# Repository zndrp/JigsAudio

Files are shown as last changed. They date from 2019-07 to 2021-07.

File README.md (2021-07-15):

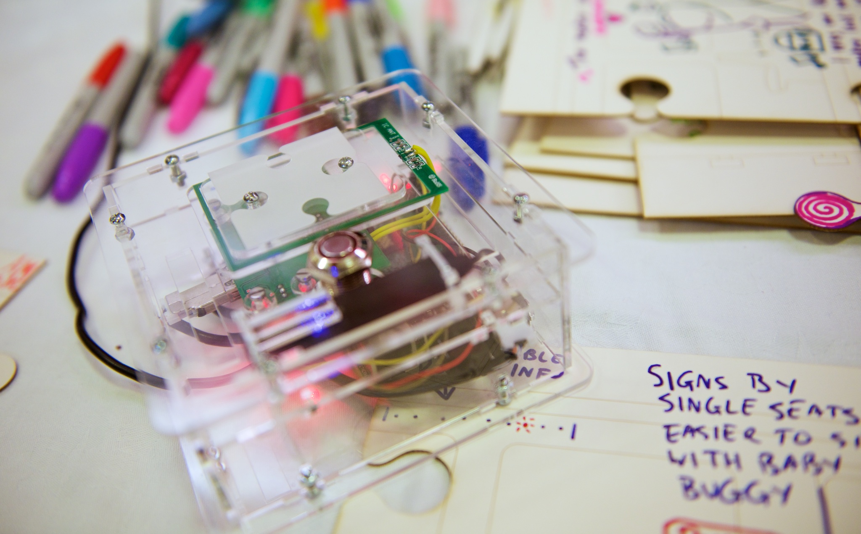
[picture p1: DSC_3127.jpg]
Image of JigsAudio


# A Few Details:

This project takes an RFID Tagged Puzzle piece and associates it with an audio clip, stored on a Raspberry Pi. I'm currently  writing instructions on how to make your own JigsAudio device, but in the meantime, please do email me: alexander.wilson@ncl.ac.uk

If you're interesting in how JigsAudio was used, you can read about it in this [paper](https://journals.sagepub.com/doi/full/10.1177/2399808319831290).

## What's inside?:
* **caseDesigns:** This folder contains the case designs for the different versions of JigsAudio (.ai and .svg). All of the cases are designed for laser cut 3mm material - usually 3mm perspex but you can what you'd like. The case requires M3 screws and nuts.

* **documentation:** This folder contains documentation on JigsAudio. This is a work in progesss. At the moment it contains the circuit schematic (showing where the leads for the buttons and switches go). 

* **jigsawDesigns:** This folder contains the desgins for the different jigsaw designs. These are easily created (as long as the peices are large enough for RFID tags).

* **templates:** The template folder contains the template for the webpage that will be generated to allow the device to be connected to and listen to the audio.

* **testingScripts:** These are scripts that were used to test the various functions of JigsAudio before they were added to the main script. They test functions such as the lights and buttons to make sure they're wired correctly.

* **website-generator:** These scripts will make the JigsAudio webpage that is used to share the results on a static website.

This project wouldn't be possible without the help and support of Samantha Finnigan, Andy Dow and Sebastian Mellor. Huge huge thanks to everyone that helped me.

This project wouldn't be possible without the help and support of Samantha Finnigan and Andy Dow. A huge huge thanks!

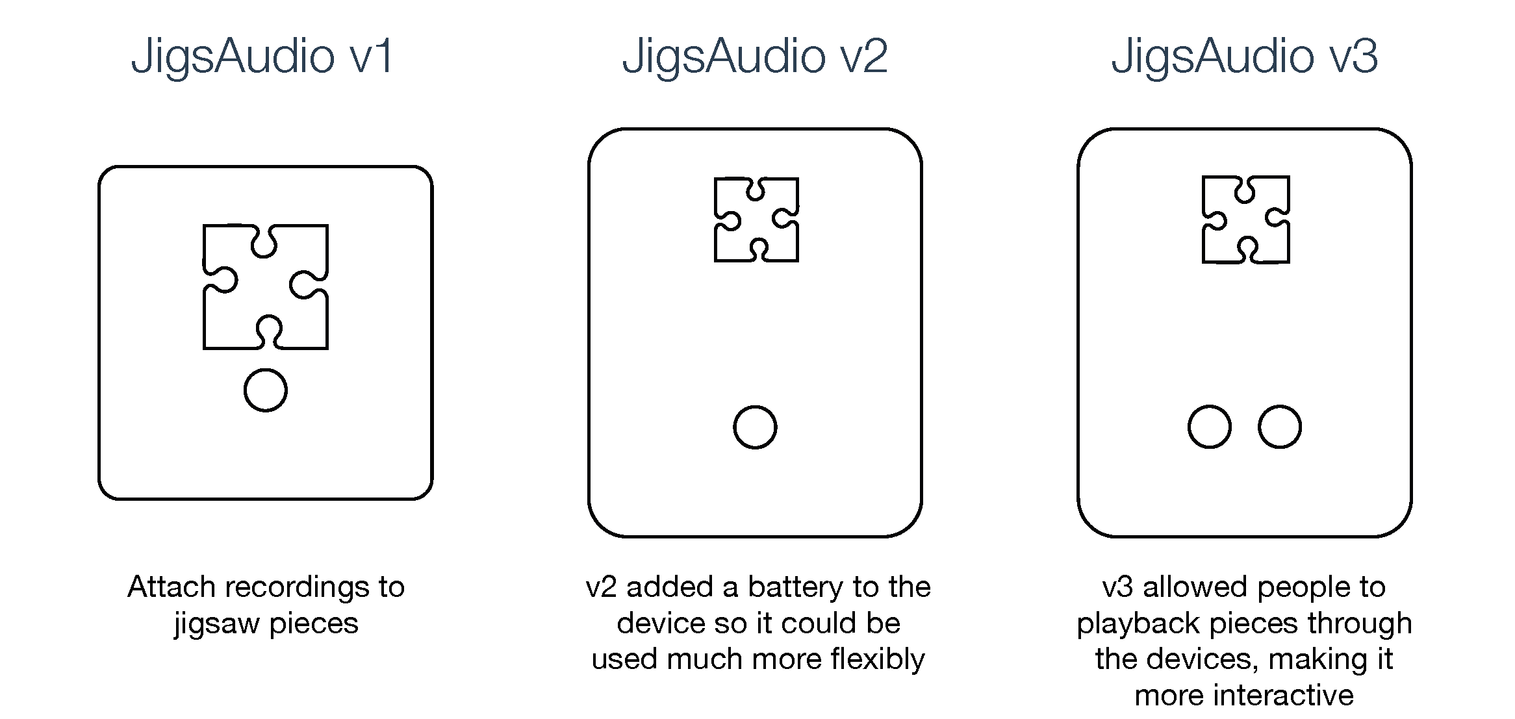
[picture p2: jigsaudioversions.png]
JigsAudio Versions

# Recommended Hardware:
The JigsAudio device is made from a number of off the shelf components, some of which are modified to fit within the case. As there are a lot of generic components within the device, the links to them change frequently. Rather than endlessly update these, the considerations for these components are listed. 
* *[USB RFID Reader](https://www.amazon.co.uk/Contactless-Proximity-Sensor-Reader-125Khz/dp/B00GS18WHS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):* USB RFID Contactless Proximity Sensor Smart: JigsAudio reads RFID tags that are attached to individual pieces. There are different types of RFID tags and readers. It’s important that these are compatible, so make sure the correct tags are purchased with the reader. When making the device, the casing for the reader is removed and the reader attached with two pieces in the top piece of the device.
* *RFID Tags - [Amazon](https://www.amazon.co.uk/gp/product/B00M5PC0FG/ref=oh_aui_detailpage_o08_s00?ie=UTF8&psc=1) or [Seritag](https://seritag.com/nfc-tags/22mm-clear-ntag213):* As above, make sure that the tags are compatible with the reader.
* *[Raspberry Pi](https://www.raspberrypi.org/products/raspberry-pi-2-model-b/):* Use a model of Raspberry Pi – most of them should work. The case is designed for full size RPs.
* *2x 16mm Momentary Push Button:* Make sure resistors are used for the LEDs within the buttons, particularly if using buttons with lower voltages than the RPi provides.
* *[USB Microphone](https://www.amazon.co.uk/Kinobo-Microphone-Desktops-Dictation-Software/dp/B00NSOWWIS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):* A generic USB microphone is used that is attached to the top case with cable ties. A cheap mic is used. Note: the sound quality playing from the RPi isn’t particually good – there is no dedicated sound card within the device. A USB sound quality can be added to JigsAudio if the audio quality is important
* *WiFI Adaptor:* (if not built into the RPi): Allows for the website to be served from the device, and to listen to and delete recordings, and verify the device is working.

# Some Final Things:
To have the JigsAudio Python script run at startup, you need to change the .bashrc file. This file can be found by typing: `sudo nano /home/pi/.bashrc` (You'll need to enter your password). When you find the file, add the following lines to the end of the file:

```
sudo nano /home/pi/.bashrc
echo Running at boot
sudo python /home/pi/JigsAudio/main.py 
```
    
Exit `ctrl + x` and reboot `sudo reboot now`

There's a few other things to do, such as set the volume of the headphones: 

Turn off Desktop Boot & Force Headphones
```
sudo raspi-config
```
Boot options > Desktop/CLI > Console Autologin
Advanced > Force Headphones

```
sudo Alsamixer
```
Turn volume up to full (using the arrow keys)

Restart the RPi
```
sudo reboot now
```

..it should now start up running JigsAudio.

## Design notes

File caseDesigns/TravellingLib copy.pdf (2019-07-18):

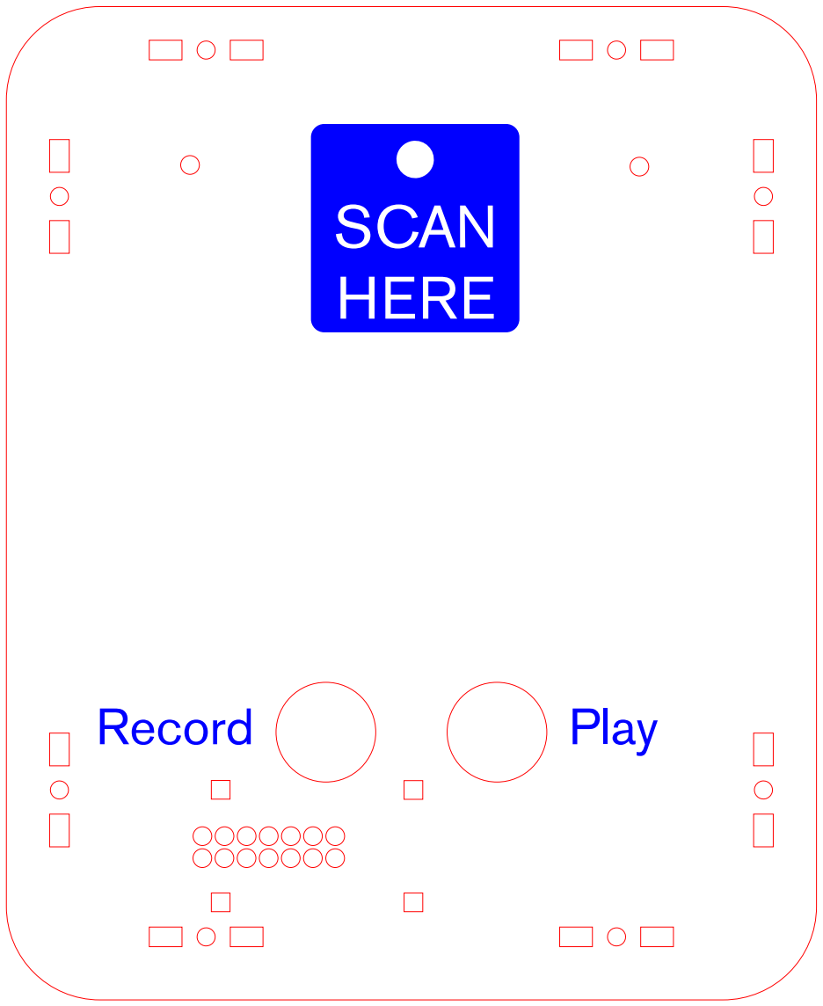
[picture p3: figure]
Record; Play; SCAN HERE

### Making a Recording

Grab a square from below
Draw your response
Scan your square and press the red button to record
Talk about your square
Press the red button to finish

### Listening to a Square

Scan someone else’s square Press the green button

BALTIC would like to acknowledge and thank Newcastle University’s Open Lab and Newcastle City Futures for JigsAudio.

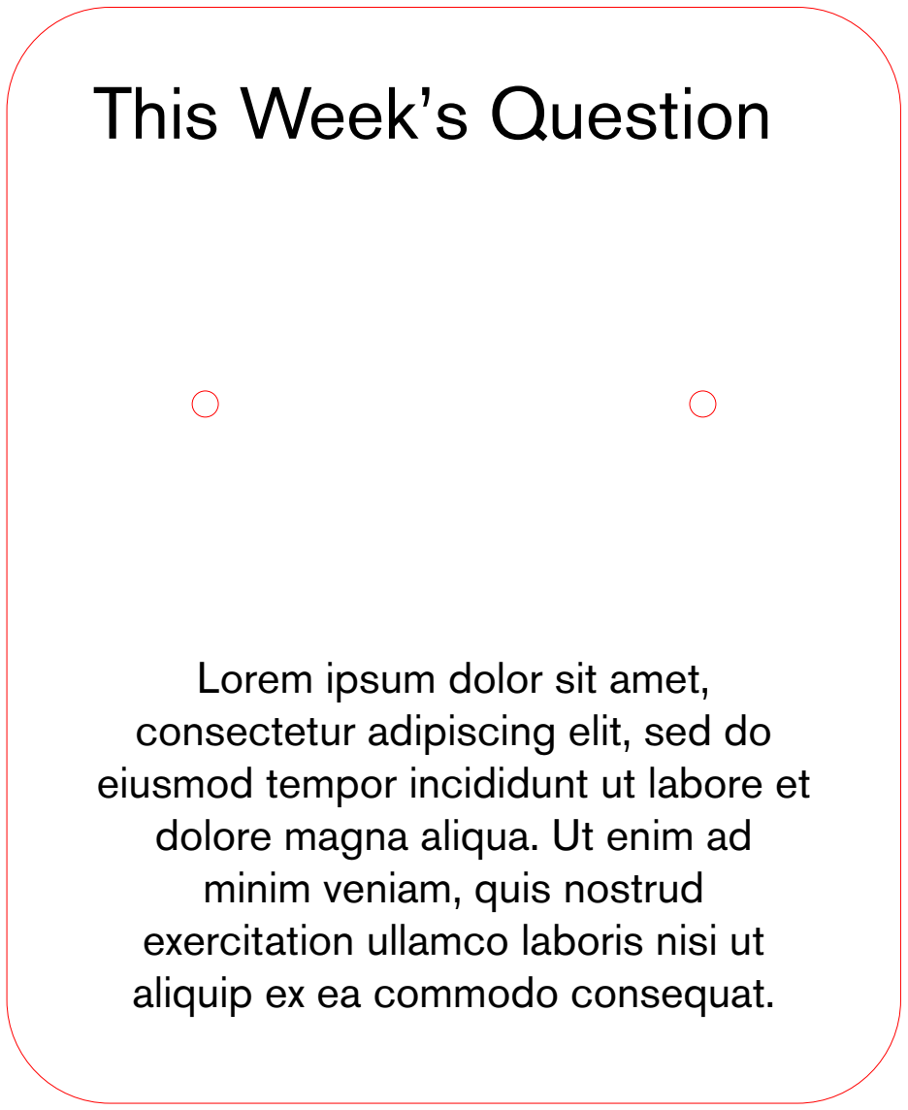
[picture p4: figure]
Lorem ipsum dolor sit amet, consectetur adipiscing elit, sed do eiusmod tempor incididunt ut labore et dolore magna aliqua. Ut enim ad minim veniam, quis nostrud exercitation ullamco laboris nisi ut aliquip ex ea commodo consequat.

Using JigsAudio | This Week’s Question

### If you could have

one superpower,

### what would it be?

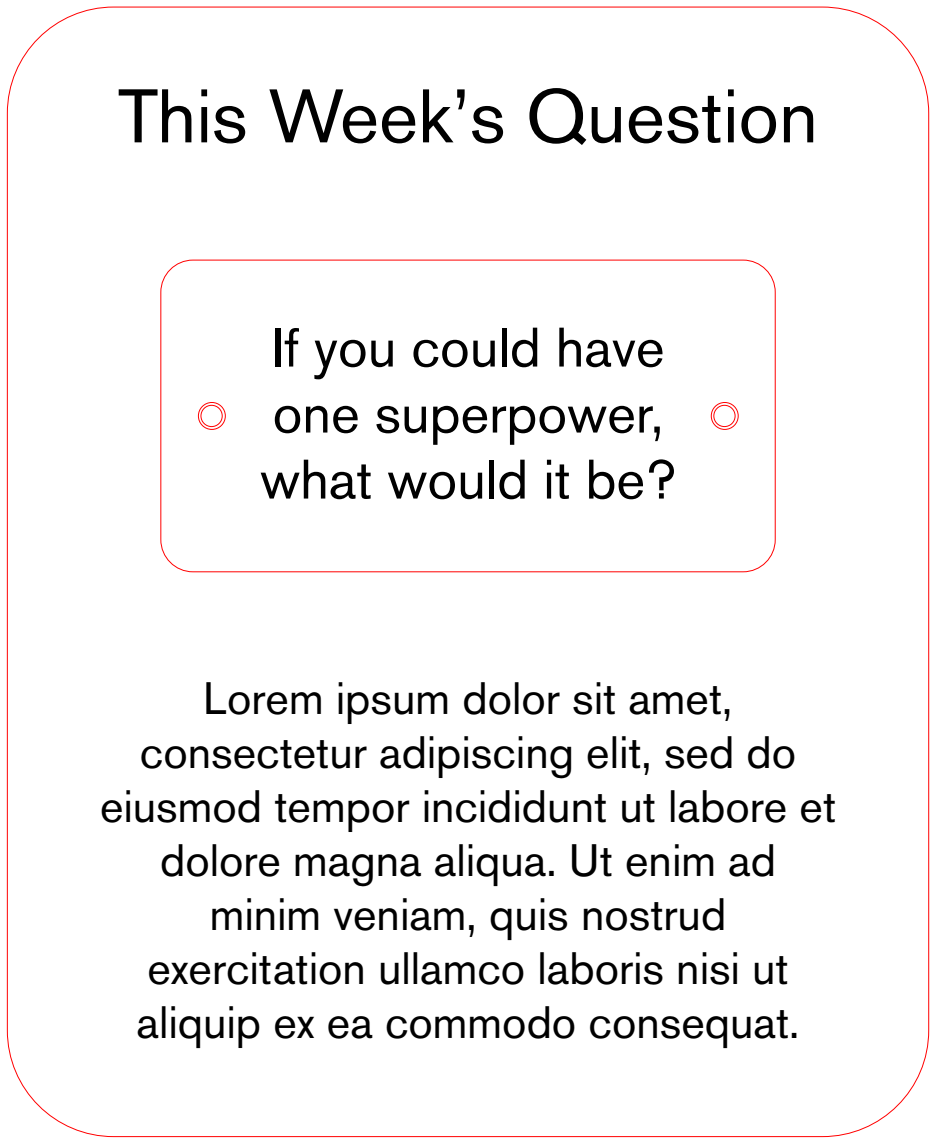
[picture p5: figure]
Lorem ipsum dolor sit amet, consectetur adipiscing elit, sed do eiusmod tempor incididunt ut labore et dolore magna aliqua. Ut enim ad minim veniam, quis nostrud exercitation ullamco laboris nisi ut aliquip ex ea commodo consequat.; This Week’s Question; If you could have one superpower, what would it be?

### What’s your favourite thing about where you live?

### How much wood could a woodchuck chuck?

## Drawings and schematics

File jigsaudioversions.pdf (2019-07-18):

JigsAudio v1 | JigsAudio v2 | JigsAudio v3

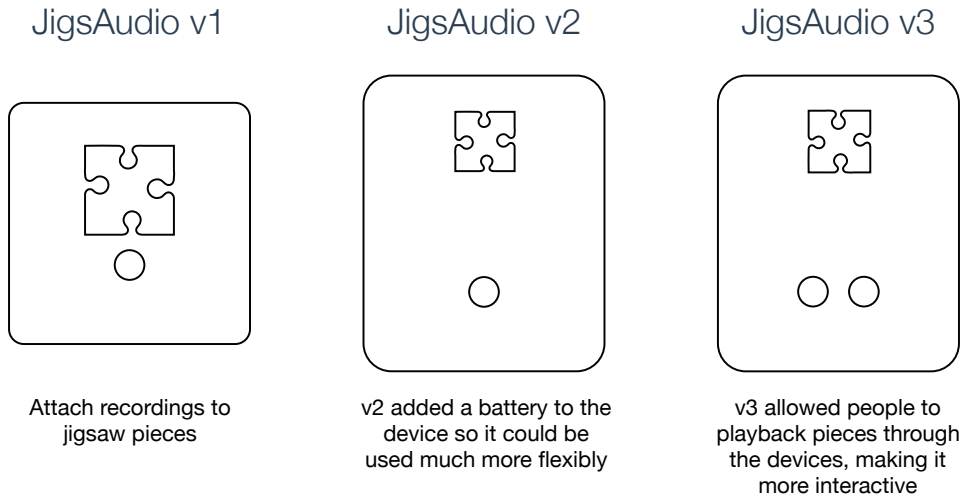
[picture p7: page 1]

Attach recordings to
jigsaw pieces

v2 added a battery to the
device so it could be
used much more flexibly

v3 allowed people to
playback pieces through
the devices, making it
more interactive

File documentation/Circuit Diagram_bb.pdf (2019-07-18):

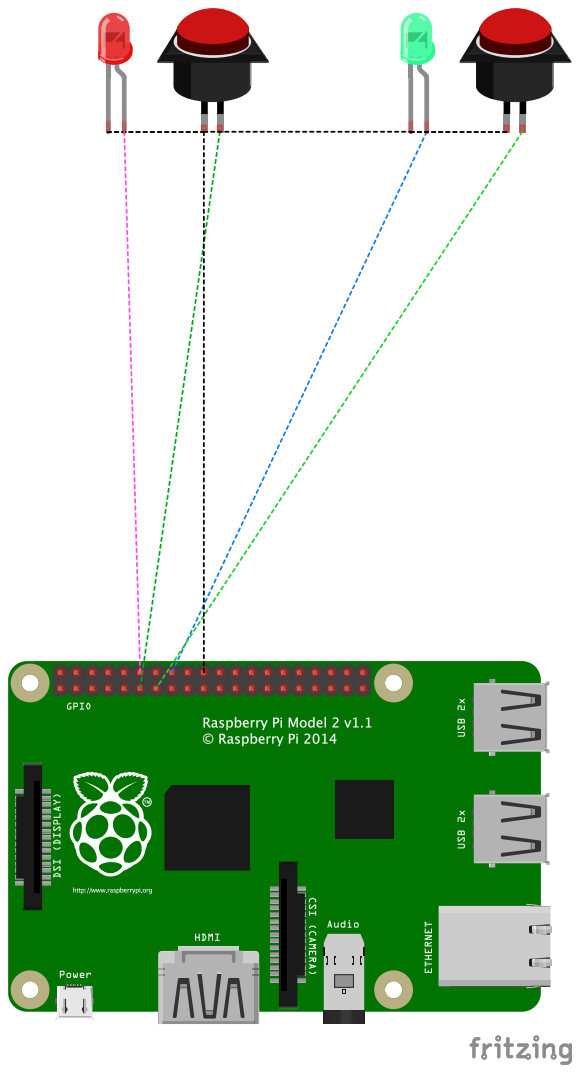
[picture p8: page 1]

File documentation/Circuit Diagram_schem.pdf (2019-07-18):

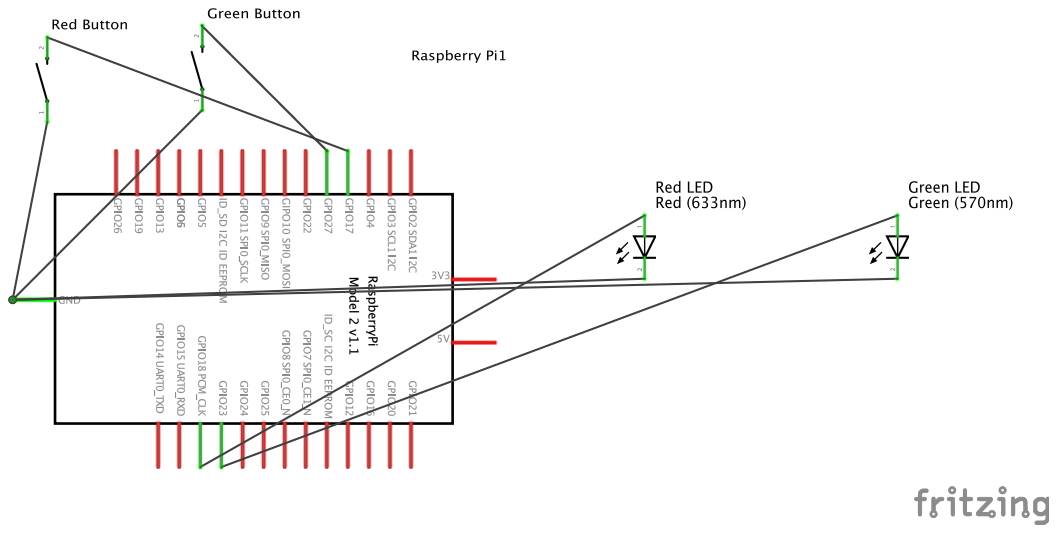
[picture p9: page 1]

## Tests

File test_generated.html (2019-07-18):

# Your JigsAudio Device

You've connected to your JigsAudio device. From here, you're able to view instructions on how to use the device, listen to and download the audio, as well as check the device's status.

JigsAudio

## Last Recording Made:

28-11-2016 16:07:28

0135428026-1.wav

## Number of Recordings:

4

## Download All

Some content here

Download All Audio

##### 0135428026-1.wav Creation DateTime 28-11-2016 16:07:28

type="audio/wav">

##### 0135428026-3.wav Creation DateTime 28-11-2016 16:08:37

type="audio/wav">

##### 0135428026-7.wav Creation DateTime 28-11-2016 16:09:43

type="audio/wav">

##### 0135428026-11.wav Creation DateTime 28-11-2016 16:17:25

type="audio/wav">

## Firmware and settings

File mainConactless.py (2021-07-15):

#/usr/bin/env python
import os
#import pyaudio
#import wave
import sys
import RPi.GPIO as GPIO
import time
import glob
#import pygame
import subprocess
#import signal
import json
from rfidkeyboard import *

#GLOBALS HERE:
#this is where the audio is going to be recorded to:
AUDIODIR = "/home/pi/audiorecordings/"
scan_time = None
#Something to do with the format - not too sure what.
#FORMAT = pyaudio.paInt16
#Change to 2 for stereo mic.
#CHANNELS = 1
#Quality of the audio recording:
#RATE = 48000
#No. of chunks. No idea what this is?!
#CHUNK = 1024
#the longest recording possible (in seconds)
RECORD_SECONDS = 120
#light_status = False


#do this before setting doing anything else.
def init():
	#setup GPIO Pins
	GPIO.setmode(GPIO.BCM)
	GPIO.setwarnings(False)

	GPIO.setup(18,GPIO.OUT) #this is the red LED
	GPIO.setup(17,GPIO.IN, pull_up_down=GPIO.PUD_UP) #this is the red button
	GPIO.setup(23,GPIO.OUT) #this is the green LED
	GPIO.setup(27,GPIO.IN, pull_up_down=GPIO.PUD_UP)
 	#this is the green button

	print "JigsAudio v3.0"

 	if os.path.isdir(AUDIODIR):
 		print "Audio Directory exists. Audio directory setup correctly"

 	if not os.path.isdir(AUDIODIR):
 		print "No Directory for Audio exists - exit the script and type: 'mkdir /home/pi/audiorecordings/'"


def captureAudio(audio_path):
	# -D plughw:CARD=Device,DEV=0
	p = subprocess.Popen("arecord -D plughw:1,0 -f S16_LE -r 48000 " + audio_path, shell=True)
	
	print "Recording..."
	recordStart = time.time()
	buttonReleased = False
	#time.sleep(2)
	while True:
		now = time.time()
		elapsed = now - recordStart
		stop = False

		if int(elapsed * 2) % 2 == 0:
			light("red","on")
		else:
			light("red","off")

		# Check if the application has already stopped (error / out of disk?)
		if p.poll() is not None:
			stop = True

		# Arm button when it's released, another press will stop the recording
		if GPIO.input(17):
			buttonReleased = True
		elif buttonReleased:
			stop = True

		# Recordings are a maximum of two minutes
		if elapsed >= RECORD_SECONDS:
			stop = True

 		if stop:
			os.system("killall arecord")
			break

		# hack to prevent the busy-wait becoming too tight
		time.sleep(.01)


	light("red", "off")
	print "finished recording as: " + audio_path

# def captureAudio(file):
# 	audio = pyaudio.PyAudio()

# 	# start Recording
# 	stream = audio.open(format=FORMAT, channels=CHANNELS,
# 	                	rate=RATE, input=True,
# 	                	frames_per_buffer=CHUNK)
# 	print "Recording..."
# 	frames = []

# 	for i in range(0, int(RATE / CHUNK * RECORD_SECONDS)):
# 		try:
# 			data = stream.read(CHUNK)

# 		except IOError as ex:
# 			print "IOError Caught!" 
# 			if ex[1] != pyaudio.paInputOverflowed:
# 				raise
# 			data = '/x00' * CHUNK

# 		frames.append(data)
# 	    #flashes the light
# 		global light_status
			
# 		if i % 24  == 0:
# 			if light_status:
# 				light("red", "off")
# 				light_status = False
# 			else:
# 				light("red", "on")
# 				light_status = True

# 		if GPIO.input(17) == False and i > 200:
# 			break


# 	print "finished recording as: " + file
#  	stop_rec(stream, audio, file, frames)


# def stop_rec (stream, audio, puz_id, frames):
# 	WAVE_OUTPUT_FILENAME = puz_id
# 	# stop Recording
# 	stream.stop_stream()
# 	stream.close()
# 	audio.terminate()

# 	waveFile = wave.open(WAVE_OUTPUT_FILENAME, 'wb')
# 	waveFile.setnchannels(CHANNELS)
# 	waveFile.setsampwidth(audio.get_sample_size(FORMAT))
# 	waveFile.setframerate(RATE)
# 	waveFile.writeframes(b''.join(frames))
# 	waveFile.close()


def light(colour, on_off):
	if colour == "red" and on_off == "on":
		GPIO.output(18,GPIO.HIGH)

	if colour == "green" and on_off == "on":
		GPIO.output(23,GPIO.HIGH)

	if colour == "red" and on_off == "off":
		GPIO.output(18,GPIO.LOW)

	if colour == "green" and on_off == "off":
		GPIO.output(23,GPIO.LOW)

	if colour == "both" and on_off == "on":
		GPIO.output(23,GPIO.HIGH)
		GPIO.output(18,GPIO.HIGH)

	if colour == "both" and on_off == "off":
		GPIO.output(23,GPIO.LOW)
		GPIO.output(18,GPIO.LOW)

	else:
		return

def light_flash(flashfrq, flashno):
	flashes = 0
	while flashes < flashno:
		GPIO.output(18,GPIO.HIGH)
		GPIO.output(23,GPIO.HIGH)
		time.sleep(flashfrq)
		GPIO.output(18,GPIO.LOW)
		GPIO.output(23,GPIO.LOW)
		time.sleep(flashfrq)
		flashes = flashes + 1

def log_interaction(type, data = {}):
    # Add our custom fields to the data
    #data['time'] = time.strftime("%Y-%m-%d %H:%M:%S")
    #data['type'] = type
    
    # Open the log file
    #try:
    #    with open('log.json', 'r') as log_file:
    #        log_data = json.load(log_file)
    #except:
    #    log_data = []
    

    # Append the new data item
    #log_data.append(data)
    
    # Write the data back to the log file
    #with open('log.json', 'w+') as log_file:
    #    log_data = json.dump(log_data, log_file)

    log_data = {}
    log_data['time'] = time.strftime("%Y-%m-%d %H:%M:%S")
    log_data['type'] = type
    log_data.update(data)
    with open('/home/pi/JigsAudio/log.json', 'a') as log_file:
        json.dump(log_data, log_file)
        log_file.write("\n")
        print "data logged"
    print "Data logged"

def main():

	while True:
		#grab the puzzle piece ID, and format it into an mp3 file
		current_time = time.time()
		print current_time
		puz_id = raw_input("What's the number of the puzzle piece? (scan the piece): ")

		if puz_id == "":
			puz_id = "NoUserInput"
		
		time_scanned = time.time()
		print time_scanned

		#this will look for the last scan. If the scan was made within 1 second of the scipt being ready, they will be discarded.
		diff_time = time_scanned - current_time
		print diff_time

		if diff_time > 1:
			break

	print puz_id
	clipno = 1
	prev_rec = False

	#It's always ready to make a recording
	#is there already audio? Find a filename to use:
	while os.path.exists(puz_id + "-" + str(clipno) + ".wav"):
		clipno = clipno + 1
		prev_rec = True
	
	puz_file = puz_id + "-" + str(clipno) + ".wav"

	#take the time the puzzle was scanned to later compare (to look for errors of multiple scans)
	scan_time = time.time()

	print "ready to record"
	light("red", "on")

	if prev_rec:
		print "ready to play"
		light("green", "on")

	tag_id = None

	while True:
		green_button = GPIO.input(27)
		red_button = GPIO.input(17)

#		tag_id = None

		with RfidReader("Sycreader RFID Technology Co., Ltd SYC ID&IC USB Reader", verbose=False) as rfid:
			while True:
				card = rfid.read()
				if card is not None:
					print("CARD: " + card)
					break
				tag_id = card
				print "escaped card read loop"

				time.sleep(0.050)

				if tag_id is not None:
					print "checking if not blank to break"
					break

			if tag_id is not None:
				break


		if tag_id is not None:
			print "contactless record protocol initiated"
			print puz_file
			record(puz_file)
			break

		if not green_button and prev_rec:
			light("red","off")
			play_piece(str(puz_id + "-1.wav"))
			break

		current_time = time.time()
		time_since_scan = current_time - scan_time

		if time_since_scan > 10:
			print "Button Not Pressed - Timed Out"
			light("both","off")
			break
	
	return True

def record(puz_id):
	light("both", "off")
	file = AUDIODIR + puz_id
	print puz_id
	print file
	captureAudio(file)

	log_interaction('recording', {
				'puzzle': puz_id,
				'file': file
			})

	print "sound recordeded to: " + puz_id
	flashfrq = 0.1
	flashno = 6
	light_flash(flashfrq, flashno)

	#this will make sure the script returns to running again
	return True

p = None

def play_piece(audio_path):
	p = subprocess.Popen("aplay " + audio_path, shell=True)
	
	light("green","on")
	print "playing"
	time.sleep(2)
	while True:
		time.sleep(.01)
#		print p.poll()
 		if p.poll() is not None or not GPIO.input(27):
#			print 'hejsan, we got i to kill'
#			p.send_signal(signal)
#			s.killpg(os.getpgid(p.pid), signal.SIGTERM)	
#			p = None	
			os.system("killall aplay")
			#put the light flashing script here

			log_interaction('play', {'id': audio_path})
			break

	light("green", "off")
	print "Clip finished"
	


if __name__ == "__main__":
	os.chdir(AUDIODIR)	
	init()
	light_flash (0.3, 6)
	light("both", "off")
	while main():
#		p = subprocess.Popen("sudo python3 testing.py")
		time.sleep(.5)
		

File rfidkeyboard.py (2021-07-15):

from __future__ import print_function   # Python 2 support for:  print(..., end=...)
import sys                              # Python 2 doesn't support print(..., flush=True)
import time
import os
import fcntl

class RfidReader:
    """
        Non-blocking raw-input reader for enter-terminated time-batched numeric input
        (e.g. M301 Mifare Card RF ID Reader)
        Dan Jackson, 2020-2021
    """

    def __init__(self, deviceName = None, verbose = False, deviceIndex = None):
        # Ensure device name is a list of allowed devices
        if deviceName is None or deviceName == "":
            self.deviceName = []
        elif isinstance(deviceName, list):
            self.deviceName = deviceName
        else:
            self.deviceName = [deviceName]
        self.verbose = verbose          # Noisy output to stdout for debugging
        self.deviceIndex = deviceIndex  # None/0=(Default) last matching device name found, 1=1st matching, ...
        self.file = None
        self.card = ""
        self.input = ""
        self.last = None
    
    def __del__(self):
        self.close()
    
    def __enter__(self):
        self.open()
        return self
    
    def __exit__(self, type, value, tb):
        self.close()
    
    def open(self):
        print("RfidReader: Opening..." + str(self.deviceName))
        inputDeviceBase = "/sys/class/input/"
        inputPathBase = "/dev/input/"
        inputDevice = None
        matchIndex = 0
        for device in os.listdir(inputDeviceBase):
            if not device.startswith("event"):
                continue
            nameFile = inputDeviceBase + device + "/device/name"
            with open(nameFile, 'r') as nf:
                name = nf.read().strip()
            print("RfidReader: Checking input [" + device + "]: '" + name + "'")
            if len(self.deviceName) > 0 and name not in self.deviceName:
                continue
            matchIndex += 1
            print("RfidReader: ...match " + str(matchIndex) + ", looking for " + str(self.deviceIndex) + "")
            if self.deviceIndex is not None and self.deviceIndex > 0 and matchIndex != self.deviceIndex:
                continue
            inputDevice = inputPathBase + device
        if inputDevice == None:
            print("RfidReader: Cannot find a matching input device: " + str(self.deviceName))
            raise Exception("Cannot find matching input device")
        print("RfidReader: Found input device: " + inputDevice)
        self.file = open(inputDevice, "rb", buffering=0)
        # Non-blocking mode
        fd = self.file.fileno()
        fcntl.fcntl(fd, fcntl.F_SETFL, fcntl.fcntl(fd, fcntl.F_GETFL) | os.O_NONBLOCK)
    
    def close(self):
        if self.file == None:
            return
        #print("RfidReader: Closing...")
        self.file.close()
        self.file = None
    
    def read(self):
        #print("RfidReader: Read...")
        self.card = ""
        now = time.time()
        if (self.input != "" and self.last != None and now - self.last > 2):
            print("RfidReader: Input timeout")
            self.input = ""
            self.last = None
        while True:
            eventData = None
            try:
                eventData = self.file.read(24)
            except IOError as e:
                if e.errno == 11: # Python 2 gets [Errno 11] Resource temporarily unavailable
                    if self.verbose:
                        print("!", end="") # flush=True (can't with Python 2 __future__ print)
                        sys.stdout.flush()
                    break
                raise

            if eventData is None: # Python 3 get no event
                if self.verbose:
                    print(".", end="") # flush=True (can't with Python 2 __future__ print)
                    sys.stdout.flush()
                #raise TypeError("No data read")
                break

            self.last = now 

            #timeS: eventData.readUInt32LE(0),
            #timeUS: eventData.readUInt32LE(4),
            #type: eventData.readUInt16LE(8),
            #code: eventData.readUInt16LE(10),
            #value: eventData.readInt32LE(12),

            # 28=Enter, 2='1', 3='2', ..., 10='9', 11='0'
            code = eventData[10]
            # 0=release, 1=press, 2=repeat
            value = eventData[12]

            # Compatibility with Python 2
            if isinstance(code, str):
                code = ord(code)
            if isinstance(value, str):
                value = ord(value)

            # Map scan code to character
            char = None
            # Main keyboard numeric input
            if code == 28: char = "\n" # 28=Main keyboard Enter key
            elif code >= 2 and code <= 11: char = str((code - 1) % 10) # Main keyboard numeric keys: 2='1', 3='2', ..., 10='9', 11='0'
            # Num-pad
            elif code == 96: char = "\n" # 96=Numpad Enter
            elif code == 82: char = "0" # 82=0 numpad
            elif code >= 79 and code <= 81: char = str(code - 79 + 1) # 79/80/81=1/2/3 numpad
            elif code >= 75 and code <= 77: char = str(code - 75 + 4) # 75/76/77=4/5/6 numpad
            elif code >= 71 and code <= 73: char = str(code - 71 + 7) # 71/72/73=7/8/9 numpad
            # Limited alpha support for hex digits (not tracking shift/caps status, so lower-case only)
            elif code == 30: char = "a"
            elif code == 48: char = "b"
            elif code == 46: char = "c"
            elif code == 32: char = "d"
            elif code == 18: char = "e"
            elif code == 33: char = "f"

            if value == 1: # pressed
                if char is not None and self.verbose:
                    print("<" +  str(code) + "=" + str(ord(char)) + "=" + char.replace("\n", "\\n") + ">", end="") # flush=True (can't with Python 2 __future__ print)
                    sys.stdout.flush()
                if (char == "\n"):                    # Keycode for enter
                    self.card = self.input
                    self.input = ""
                elif char is not None:      # Keycode for decimal digit: 2='1', 3='2', ..., 10='9', 11='0'
                    self.input = self.input + char
                else:
                    # Unhandled scan code
                    if self.verbose:
                        print("[?" + str(code) + "]", end="") # flush=True (can't with Python 2 __future__ print)
                        sys.stdout.flush()
                    pass
        
        # No card found / cards exist
        if self.card == "":
            return None
        return self.card
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

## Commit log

2019-07-18 first comit
    comit
    [Circuit Diagram.fzz]
2021-06-10 mini case
2021-07-15 rfid interrupt
